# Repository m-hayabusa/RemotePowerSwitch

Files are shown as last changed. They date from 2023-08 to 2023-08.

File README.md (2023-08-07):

# M5Stamp C3 を PC のフロントパネルヘッダに繋いで、電源を Wi-Fi 越しに操作するやつ



## 必要なもの

-   基板
-   1 x M5Stamp C3 Mate あるいは M5Stamp C3U Mate
    -   Mate のセットでなく単体の場合は、適当なロープロファイルピンヘッダとピンソケットも用意してください
-   5 x 1608 チップ抵抗 / 100Ω 程度
-   3 x SOT-23 Nch MOSFET / BSS138 など
-   1 x SOD-123 定電流ダイオード or 定電流レギュレータ / 20mA 程度 NSI45020AT1G など
-   1 x L 字ピンヘッダー / 2.54 mm ピッチ 1 列 5 ピン
-   1 x L 字ピンソケット / 2.54 mm ピッチ 2 列 5 ピン

## つくりかた

-   下: GND ベタがないほう
-   表面: 表面実装部品のパターンがある面
-   裏面: LED+/LED-/PWR#/GND/NC の印字がある面

1. 表面に、定電流ダイオードと MOSFET をはんだづけする
2. 表面に、抵抗をはんだづけする。下から 5 つ
3. 裏面に、1x5 のピンヘッダをはんだづけする。LED+/LED-/PWR#/GND/NC の印字が見える方向
4. M5Stamp C3 に付属のピンヘッダを、M5Stamp にはんだづけする
5. 表面に、M5Stamp C3 に付属のピンソケットをはんだづけする。
   あるいは、M5Stamp につけたピンヘッダを直接基板にはんだづけしてもよい
6. 表面に、2x5 のピンソケットをはんだづけする。
   シルクで印がしてあるピンはマザーボード側で欠けてあるピンなので、可能ならソケットからピンを抜いて UV レジンか何かで埋めておくとよい
7. M5Stamp にファームウェアを書きこむ

## ファームウェアの書き込み; 初回

1. VisualStudio Code にプラグイン PlatformIO を追加
2. https://github.com/m-hayabusa/RemotePowerSwitch.git を clone する
3. PlatformIO で 2. のディレクトリを開く。VSCode の左側のバー、なんか触覚が生えてる顔のアイコンから
4. 下のバーの「Default (RemotePowerSwitch)」の部分をクリック、M5Stamp-C3 か M5Stamp-C3U かを選択
5. 下のバーの「→」をクリック、Upload
6. 適当なシリアルモニターで M5Stamp のポートを開く。PlatformIO なら画面下のバーのプラグのアイコンから。挙動が怪しいような気がするので Arduino IDE のシリアルモニタがおすすめ
7. シリアルモニターでこれらを送って設定:

```
WIFI.SSID:(2.4GHz な Wi-Fi ネットワークの SSID)
WIFI.PASSWORD:(Wi-Fi ネットワークのパスワード)
WEB.HOSTNAME:(mDNS で宣伝するホスト名)
WEB.PASSWORD:(Webページから操作するときに必要なパスワード, 設定しなければパスワードなしで操作できます / 解除する場合は空の文字列を設定)
```

8. "http://" + WEB.HOSTNAME + ".local"で接続できるはずです

## ファームウェアの更新

1. PlatformIO でファームウェアをビルド (下のバーの「✔️」)
2. "http://" + WEB.HOSTNAME + ".local/update" をブラウザで開く
3. Firmware.bin のボタンをクリック、プロジェクトのディレクトリ/.pio/M5Stamp-C3/firmware.bin を選択
4. Upload をクリック
5. アップロード・書き込みが終わると自動で再起動します

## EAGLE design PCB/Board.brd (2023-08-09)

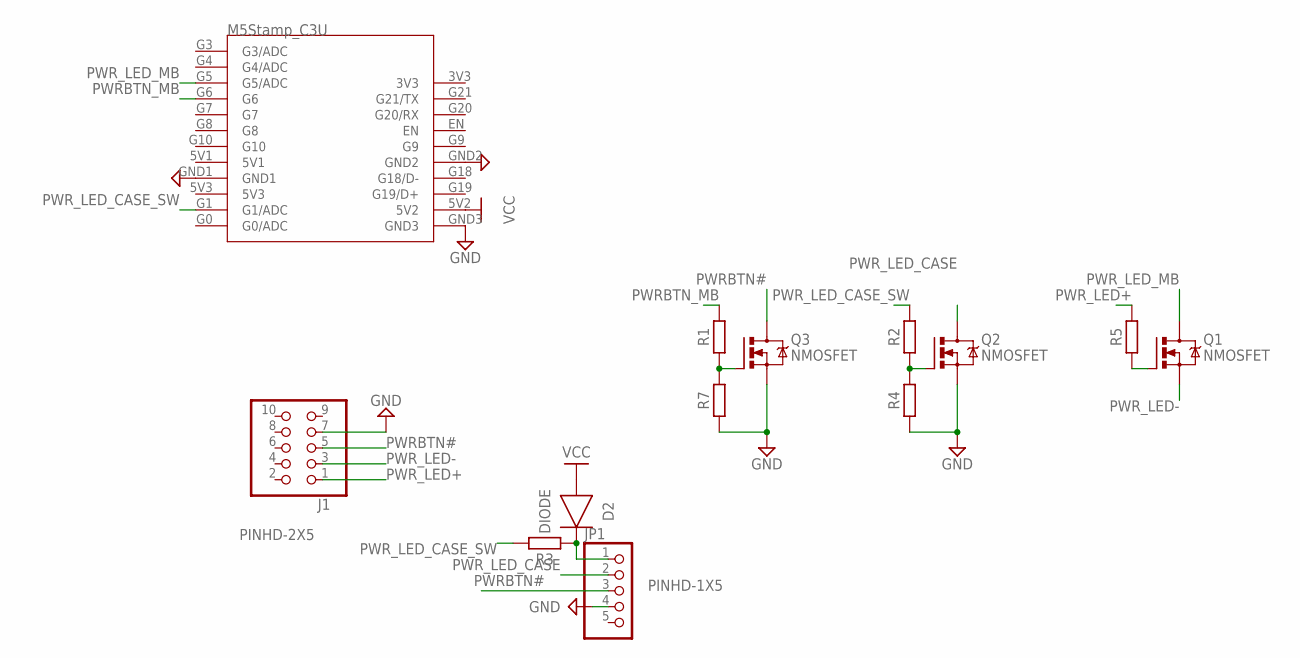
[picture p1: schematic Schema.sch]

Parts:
D2: DIODE; SODFL3718X115
J1: PINHD-2X5; 2X05
JP1: PINHD-1X5; 1X05
Q1, Q2, Q3: NMOSFET; SOT23
R1, R2, R3, R4, R5, R7: R_CHIP-0603(1608-METRIC); RESC1608X60
U$1: M5STAMP_C3UHEADER; M5STAMP_C3U_HEADER

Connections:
GND: J1.7, JP1.4, Q2.2 (S), Q3.2 (S), R4.1, R7.1, U$1.GND1, U$1.GND2, U$1.GND3
unnamed: Q3.1 (G), R1.1, R7.2
unnamed: Q2.1 (G), R2.1, R4.2
unnamed: D2.1 (C), JP1.1, R3.1
unnamed: Q1.1 (G), R5.1
PWRBTN#: J1.5, JP1.3, Q3.3 (D)
PWRBTN_MB: R1.2, U$1.G6
PWR_LED+: J1.1, R5.2
PWR_LED-: J1.3, Q1.2 (S)
PWR_LED_CASE: JP1.2, Q2.3 (D)
PWR_LED_CASE_SW: R2.2, R3.2, U$1.G1 (G1/ADC)
PWR_LED_MB: Q1.3 (D), U$1.G5 (G5/ADC)
VCC: D2.2 (A), U$1.5V2

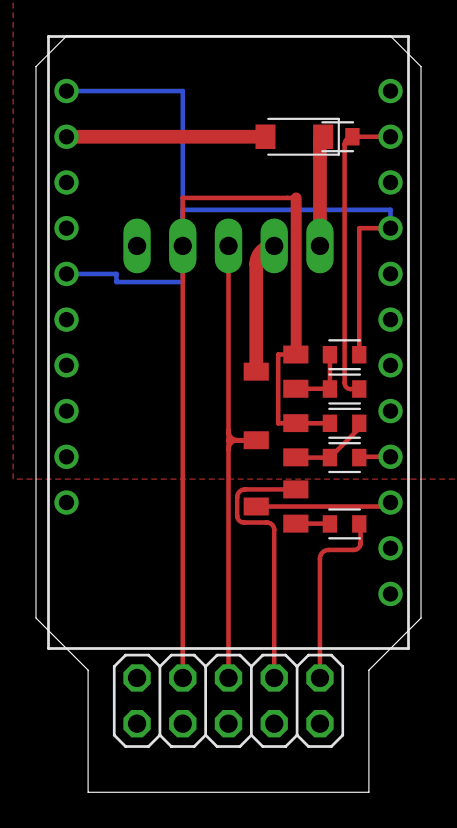
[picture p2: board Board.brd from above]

Board: 2 copper layers, 21.4 x 42.0 mm, 13 parts (1 on the bottom side), 13 nets.

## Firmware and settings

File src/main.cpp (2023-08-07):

#include <ESPmDNS.h>
#include <Preferences.h>
#include <Update.h>
#include <WebServer.h>
#include <WiFi.h>

#define PIN_PWRLED_MB 5
#define PIN_HDDLED_MB 4
#define PIN_PWRBTN_MB 6
#define PIN_RSTBTN_MB 7

#define PIN_PWRLED_CASE 1
#define PIN_HDDLED_CASE 10
#define PIN_PWRBTN_CASE 0
#define PIN_RSTBTN_CASE 8

TaskHandle_t taskHandle[7];

bool pwrLedState = false;
bool hddLedState = false;
bool powerctl = false;

enum class PowerState { Off, On, Sleep };
PowerState powerState = PowerState::Off;
Preferences Config;

void httpServer(void *pvParameters);
void PwrLedControl(void *pvParameters);
void PwrControl(void *pvParameters);
void LedPwm(void *pvParameters);
void PowerButton(void *pvParameters);
void SerialInput(void *pvParameters);

void setup() {
  Serial.begin(115200);
  Serial.println("hello");

  pinMode(PIN_PWRLED_CASE, OUTPUT);
  pinMode(PIN_HDDLED_CASE, OUTPUT);
  pinMode(PIN_PWRBTN_CASE, INPUT_PULLUP);
  pinMode(PIN_RSTBTN_CASE, INPUT_PULLUP);

  pinMode(PIN_PWRLED_MB, INPUT_PULLUP);
  pinMode(PIN_HDDLED_MB, INPUT_PULLUP);
  pinMode(PIN_PWRBTN_MB, OUTPUT);
  pinMode(PIN_RSTBTN_MB, OUTPUT);

  Config.begin("config");

  xTaskCreatePinnedToCore(httpServer, "web", 8192, NULL, 10, &taskHandle[0], 1);
  xTaskCreatePinnedToCore(PwrLedControl, "led", 1024, NULL, 5, &taskHandle[1], 0);
  xTaskCreatePinnedToCore(PwrControl, "pwr", 1024, NULL, 15, &taskHandle[2], 0);
  xTaskCreatePinnedToCore(LedPwm, "pwm", 1024, NULL, 6, &taskHandle[3], 0);
  xTaskCreatePinnedToCore(PowerButton, "btn", 1024, NULL, 20, &taskHandle[4], 0);
  xTaskCreatePinnedToCore(SerialInput, "ser", 4096, NULL, 0, &taskHandle[5], 1);

  Serial.println("nya");
}

void SerialInput(void *pvParameters) {
  String raw = "";
  Serial.setTimeout(1);
  while (1) {
    delay(10);

    if (Serial.available() > 0) {
      while (Serial.available() > 0) {
        char c = Serial.read();

        if (c == 0x0D) continue;
        if (c == 0x08) raw[raw.length() - 1] = 0;

        Serial.print(c);
        raw += c;
      }

      const int nl = raw.indexOf('\n');

      if (nl != -1) {
        const String line = raw.substring(0, nl);
        Serial.println(line);
        raw = raw.substring(nl + 1);

        const int splitter = line.indexOf(':');

        if (splitter != -1) {
          String name = line.substring(0, splitter);
          String data = line.substring(splitter + 1);
          Serial.println(name + " : " + data);
          if (name == "WIFI.SSID" || name == "WIFI.PASSWORD" || name == "WEB.PASSWORD" || name == "WEB.HOSTNAME") {
            Config.putString(name.c_str(), data);
            Serial.println(name + ":" + Config.getString(name.c_str()) + ", saved");
            if (name == "WIFI.SSID" || name == "WIFI.PASSWORD") {
              WiFi.disconnect();
              WiFi.begin(Config.getString("WIFI.SSID").c_str(), Config.getString("WIFI.PASSWORD").c_str());
            } else if (name == "WEB.HOSTNAME") {
              MDNS.end();
              delay(100);
              MDNS.begin(Config.getString("WEB.HOSTNAME", "RemotePowerButton").c_str());
              MDNS.addService("http", "tcp", 80);
            }
          } else {
            Serial.println(name + " is not in list");
          }
        } else if (line == "WIFI.SSID" || line == "WIFI.PASSWORD" || line == "WEB.PASSWORD" || line == "WEB.HOSTNAME") {
          Serial.println(line + ":" + Config.getString(line.c_str()));
        } else if (line == "REBOOT") {
          ESP.restart();
        } else {
          Serial.println("> KEY:VALUE");
        }
      }
    }
  }
}

void LedPwm(void *pvParameters) {
  ledcSetup(0, 12800, 8);
  ledcAttachPin(PIN_PWRLED_CASE, 0);
  ledcSetup(1, 12800, 8);
  ledcAttachPin(PIN_HDDLED_CASE, 1);

  int pwrlevel = 0;
  int hddlevel = 0;

  while (1) {
    if (pwrLedState)
      pwrlevel += 24;
    else
      pwrlevel -= 16;

    if (pwrlevel > 256)
      pwrlevel = 256;
    else if (pwrlevel < 0)
      pwrlevel = 0;

    ledcWrite(0, pwrlevel);

    int state = !digitalRead(PIN_HDDLED_MB);
    if (state)
      hddlevel += 32;
    else
      hddlevel -= 32;

    if (hddlevel > 256)
      hddlevel = 256;
    else if (hddlevel < 0)
      hddlevel = 0;

    ledcWrite(1, hddlevel);

    delay(20);
  }
}

void PwrLedControl(void *pvParameters) {
  Serial.println("ledControl");
  while (1) {
    switch (powerState) {
      case PowerState::On:
        pwrLedState = true;
        delay(2900);
        break;

      case PowerState::Sleep:
        pwrLedState = true;
        delay(1000);
        pwrLedState = false;
        delay(1000);
        break;

      case PowerState::Off:
        pwrLedState = true;
        delay(100);
        pwrLedState = false;
        delay(2900);
        break;
    }
    if (!WiFi.isConnected()) {
      delay(200);
      for (int i = 0; i < 3; i++) {
        pwrLedState = true;
        delay(100);
        pwrLedState = false;
        delay(200);
      }
    }
  }
}

void PowerButton(void *pvParameters) {
  while (1) {
    if (!powerctl) {
      digitalWrite(PIN_PWRBTN_MB, !digitalRead(PIN_PWRBTN_CASE));
    }
    delay(10);
  }
}

void PwrControl(void *pvParameters) {
  Serial.println("PwrControl");
  int counter = 0;

  while (1) {
    if (!digitalRead(PIN_PWRLED_MB))
      counter++;
    else
      counter--;

    if (counter <= 0) {
      powerState = PowerState::Off;
      counter = 1;
    } else if (counter >= 15) {
      powerState = PowerState::On;
      counter = 14;
    } else {
      powerState = PowerState::Sleep;
    }

    delay(100);
  }
}

WebServer *server;

void httpServer(void *pvParameters) {
  Serial.println("httpServer");

  WiFi.mode(WIFI_MODE_STA);
  WiFi.setAutoReconnect(true);
  WiFi.enableIpV6();

  server = new WebServer(80);

  WiFi.onEvent([](WiFiEvent_t event) {
    switch (event) {
      case ARDUINO_EVENT_WIFI_READY:
        Serial.println("WiFi interface ready");
        break;
      case ARDUINO_EVENT_WIFI_STA_START:
        Serial.println("WiFi client started");
        break;
      case ARDUINO_EVENT_WIFI_STA_STOP:
        Serial.println("WiFi clients stopped");
        break;
      case ARDUINO_EVENT_WIFI_STA_CONNECTED:
        Serial.println("Connected to access point");
        break;
      case ARDUINO_EVENT_WIFI_STA_DISCONNECTED:
        server->close();
        MDNS.end();
        Serial.println("Disconnected from WiFi access point");
        WiFi.reconnect();
        break;
      case ARDUINO_EVENT_WIFI_STA_GOT_IP:
        server->begin();
        MDNS.begin(Config.getString("WEB.HOSTNAME", "RemotePowerButton").c_str());
        MDNS.addService("http", "tcp", 80);
        Serial.print("Obtained IP address: ");
        Serial.println(WiFi.localIP());
        break;
      case ARDUINO_EVENT_WIFI_STA_GOT_IP6:
        server->begin();
        MDNS.begin(Config.getString("WEB.HOSTNAME", "RemotePowerButton").c_str());
        MDNS.addService("http", "tcp", 80);
        Serial.println("STA IPv6 is preferred");
        Serial.println(WiFi.localIPv6());
        break;
      case ARDUINO_EVENT_WIFI_STA_LOST_IP:
        server->close();
        MDNS.end();
        Serial.println("Lost IP address and IP address is reset to 0");
        WiFi.reconnect();
        break;
      default:
        break;
    }
  });

  WiFi.begin(Config.getString("WIFI.SSID").c_str(), Config.getString("WIFI.PASSWORD").c_str());

  server->on("/", []() {
    if (server->method() != HTTPMethod::HTTP_GET) {
      server->send(405, "text/plain", "GET Only");
      return;
    }
#include "index.html.cpp"
    server->send(200, "text/html", INDEX_HTML);
  });

  server->on("/state", []() {
    if (server->method() != HTTPMethod::HTTP_GET) {
      server->send(405, "text/plain", "GET Only");
      return;
    }
    String result = "{\"state\":\"";
    switch (powerState) {
      case PowerState::On:
        result += "On";
        break;
      case PowerState::Sleep:
        result += "Sleep";
        break;
      case PowerState::Off:
        result += "Off";
        break;
    }
    result += "\"}";

    server->send(200, "application/json", result);
  });

  server->on("/name", []() {
    if (server->method() != HTTPMethod::HTTP_GET) {
      server->send(405, "text/plain", "GET or POST");
    }
    String result = "{\"name\":\"";
    result += Config.getString("WEB.HOSTNAME");
    result += "\"}";
    server->send(200, "application/json", result);
    return;
  });

  server->on("/on", []() {
    if (server->method() != HTTPMethod::HTTP_POST) {
      server->send(405, "text/plain", "POST Only");
      return;
    }
    if (!server->authenticate(Config.getString("WEB.HOSTNAME").c_str(), Config.getString("WEB.PASSWORD").c_str())) {
      server->send(401, "text/plain", "not authorized");
      return;
    }
    if (powerState != PowerState::On) {
      server->send(202, "text/plain", "triggered");
      powerctl = true;
      digitalWrite(PIN_PWRBTN_MB, true);
      delay(100);
      digitalWrite(PIN_PWRBTN_MB, false);
      powerctl = false;
    } else {
      server->send(409, "text/plain", "already on");
    }
  });

  server->on("/off", []() {
    if (server->method() != HTTPMethod::HTTP_POST) {
      server->send(405, "text/plain", "POST Only");
      return;
    }
    if (!server->authenticate(Config.getString("WEB.HOSTNAME").c_str(), Config.getString("WEB.PASSWORD").c_str())) {
      server->send(401, "text/plain", "not authorized");
      return;
    }
    if (powerState == PowerState::On) {
      server->send(202, "text/plain", "triggered");
      powerctl = true;
      digitalWrite(PIN_PWRBTN_MB, true);
      delay(100);
      digitalWrite(PIN_PWRBTN_MB, false);
      powerctl = false;
    } else {
      server->send(409, "text/plain", "already off");
    }
  });

  server->on("/force-off", []() {
    if (server->method() != HTTPMethod::HTTP_POST) {
      server->send(405, "text/plain", "POST Only");
      return;
    }
    if (!server->authenticate(Config.getString("WEB.HOSTNAME").c_str(), Config.getString("WEB.PASSWORD").c_str())) {
      server->send(401, "text/plain", "not authorized");
      return;
    }
    if (powerState != PowerState::Off) {
      server->send(202, "text/plain", "force power off");
      powerctl = true;
      digitalWrite(PIN_PWRBTN_MB, true);
      delay(5000);
      digitalWrite(PIN_PWRBTN_MB, false);
      powerctl = false;
    } else {
      server->send(409, "text/plain", "already off");
    }
  });

  server->on("/update", HTTP_GET, []() {
#include "update.html.cpp"
    server->send(200, "text/html", UPDATE_HTML);
  });
  // OTA Update
  server->on(
      "/firmware", HTTP_POST,
      []() {
        server->sendHeader("Connection", "close");
        if (Update.hasError()) {
          server->send(500, "text/plain", Update.errorString());
        } else {
          server->send(200, "text/plain", "update done");
          ESP.restart();
        }
      },
      []() {
        HTTPUpload &upload = server->upload();

        switch (upload.status) {
          case UPLOAD_FILE_START:
            Update.begin();
            break;

          case UPLOAD_FILE_WRITE:
            Update.write(upload.buf, upload.currentSize);
            break;

          case UPLOAD_FILE_END:
            if (Update.end(true))
              Serial.printf("written %u / Restart", upload.totalSize);
            else
              Update.printError(Serial);
            break;

          case UPLOAD_FILE_ABORTED:
            Update.abort();
            break;
        }
      });
  server->on("/firmware", HTTP_GET, []() { server->send(405, "Method Not Allowed"); });

  while (1) {
    server->handleClient();
    delay(10);
  }
}

void loop() {}

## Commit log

2023-01-12 C3UでUSBシリアルを使うときの設定
2023-01-12 HTMLファイルの挿入方法を変更
2023-01-12 OTAアップデートできるように
2023-01-12 トップページをいい感じに
2023-01-12 初期化処理をsetupからそれぞれのタスクに移動
2023-01-12 トップページを携帯で見たときいい感じに
2023-01-13 グローバルな変数を減らす
2023-01-17 pinModeの設定ミス
2023-03-30 staticである意味がなかったので外した
2023-03-30 シリアルの受信バッファに何もないとき、待機せずループしていたのを修正
2023-03-30 光り方の違いがそこまでないのでsinを通すのをやめた
2023-03-30 シリアル通信の速度を変更
2023-03-31 パスを相対で指定するように変更
2023-03-31 見た目の調整
2023-03-31 シリアルの読み込み待機を減らした
2023-03-31 タスクの割り当てを変更
2023-04-01 フォーマッタの設定
2023-06-04 再起動できるように
2023-06-04 Wi-Fiから切断されたとき、再接続するように
2023-06-06 Wi-Fiに再接続したとき、IPを取得できないことがあったのを修正
2023-07-12 基板のデータを追加 (Fusion 360 / EasyEDA)
    [Board.brd, Schema.sch]
2023-07-30 つくりかたを追記
2023-08-07 CRを無視するように
2023-08-07 PlatformIOのシリアルモニタから正しく設定できるように
2023-08-09 基板を更新: LEDを5Vから駆動するようにしたりRESET / HDDLEDを触らないようにしたり
    [Board.brd, Schema.sch]
